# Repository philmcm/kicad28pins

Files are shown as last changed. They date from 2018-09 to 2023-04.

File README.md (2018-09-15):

Adaptation of 28-PINS PROJECT by FEDEVEL ACADEMY to KiCad
http://www.28pins.com

Adaptation by Phil McMillan, September 2018

(c) 2015 Designed by FEDEVEL Academy http://www.fedevel.com/academy. Based on Arduino: http://www.arduino.cc. Released under Creative Commons Attribution-ShareAlike 3.0 Unported.

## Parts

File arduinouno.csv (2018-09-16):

Source: | /Users/phil/Documents/Kicad/arduinouno/arduinouno.sch
Date: | Sunday, 16 September 2018 at 09:47:21 pm
Tool: | Eeschema (5.0.0-3-g5ebb6b6)
Generator: | /private/var/folders/0l/vnx5ky0j3ts2193kl5yxnbs00000gn/T/AppTranslocation/A56F1F43-A0CA-4C13-8180-FD3DEFA6E32C/d/kicad.app/Contents/SharedSupport/plugins/bom_csv_grouped_by_value.py
Component Count: | 108
Individual Components:
Item | Qty | Reference(s) | Value | LibPart | Footprint | Datasheet | Digikey
 |  | C1 | 100u|10V | arduinouno:EEE-1AA101WR | arduinouno:C_ALUM_C_SIZE | https://industrial.panasonic.com/cdbs/www-data/pdf/RDE0000/ABA0000C1145.pdf | PCE3867TR-ND
 |  | C2 | 100uF|10V | arduinouno:EEE-1AA101WR | arduinouno:C_ALUM_C_SIZE | https://industrial.panasonic.com/cdbs/www-data/pdf/RDE0000/ABA0000C1145.pdf | PCE3867TR-ND
 |  | C3 | 10uF|16V | arduinouno:C2012X5R1C106M085AC | arduinouno:C0805x145mm | https://product.tdk.com/info/en/catalog/datasheets/mlcc_commercial_general_en.pdf | 445-7645-1-ND
 |  | C4 | 100nF | arduinouno:C2012X7R1H104K085AA | arduinouno:C0805x95mm | https://product.tdk.com/info/en/catalog/datasheets/mlcc_commercial_general_en.pdf | 445-7534-1-ND
 |  | C5 | 100nF | arduinouno:C2012X7R1H104K085AA | arduinouno:C0805x95mm | https://product.tdk.com/info/en/catalog/datasheets/mlcc_commercial_general_en.pdf | 445-7534-1-ND
 |  | C6 | 100nF | arduinouno:C2012X7R1H104K085AA | arduinouno:C0805x95mm | https://product.tdk.com/info/en/catalog/datasheets/mlcc_commercial_general_en.pdf | 445-7534-1-ND
 |  | C7 | 1uF|25V | arduinouno:C2012X5R1E105K125AA | arduinouno:C0805x95mm | https://product.tdk.com/info/en/catalog/datasheets/mlcc_commercial_general_en.pdf | 445-1419-1-ND
 |  | C8 | 100nF | arduinouno:C2012X7R1H104K085AA | arduinouno:C0805x95mm | https://product.tdk.com/info/en/catalog/datasheets/mlcc_commercial_general_en.pdf | 445-7534-1-ND
 |  | C9 | 18pF | arduinouno:C0805C180J1GACTU | arduinouno:C0805x95mm | https://api.kemet.com/component-edge/download/datasheet/C0805C180J1GACTU.pdf | 399-8029-1-ND
 |  | C10 | 18pF | arduinouno:C0805C180J1GACTU | arduinouno:C0805x95mm | https://api.kemet.com/component-edge/download/datasheet/C0805C180J1GACTU.pdf | 399-8029-1-ND
 |  | C11 | 100nF | arduinouno:C2012X7R1H104K085AA | arduinouno:C0805x95mm | https://product.tdk.com/info/en/catalog/datasheets/mlcc_commercial_general_en.pdf | 445-7534-1-ND
 |  | C12 | 10uF|16V | arduinouno:C2012X5R1C106M085AC | arduinouno:C0805x145mm | https://product.tdk.com/info/en/catalog/datasheets/mlcc_commercial_general_en.pdf | 445-7645-1-ND
 |  | C13 | 10uF|16V | arduinouno:C2012X5R1C106M085AC | arduinouno:C0805x145mm | https://product.tdk.com/info/en/catalog/datasheets/mlcc_commercial_general_en.pdf | 445-7645-1-ND
 |  | C14 | 100nF | arduinouno:C2012X7R1H104K085AA | arduinouno:C0805x95mm | https://product.tdk.com/info/en/catalog/datasheets/mlcc_commercial_general_en.pdf | 445-7534-1-ND
 |  | C15 | 100nF | arduinouno:C2012X7R1H104K085AA | arduinouno:C0805x95mm | https://product.tdk.com/info/en/catalog/datasheets/mlcc_commercial_general_en.pdf | 445-7534-1-ND
 |  | C16 | 100nF | arduinouno:C2012X7R1H104K085AA | arduinouno:C0805x95mm | https://product.tdk.com/info/en/catalog/datasheets/mlcc_commercial_general_en.pdf | 445-7534-1-ND
 |  | C17 | 100nF | arduinouno:C2012X7R1H104K085AA | arduinouno:C0805x95mm | https://product.tdk.com/info/en/catalog/datasheets/mlcc_commercial_general_en.pdf | 445-7534-1-ND
 |  | C19 | 10uF|16V | arduinouno:C2012X5R1C106M085AC | arduinouno:C0805x145mm | https://product.tdk.com/info/en/catalog/datasheets/mlcc_commercial_general_en.pdf | 445-7645-1-ND
 |  | C20 | 100nF | arduinouno:C2012X7R1H104K085AA | arduinouno:C0805x95mm | https://product.tdk.com/info/en/catalog/datasheets/mlcc_commercial_general_en.pdf | 445-7534-1-ND
 |  | C21 | 10uF|16V | arduinouno:C2012X5R1C106M085AC | arduinouno:C0805x145mm | https://product.tdk.com/info/en/catalog/datasheets/mlcc_commercial_general_en.pdf | 445-7645-1-ND
 |  | C22 | 10uF|16V | arduinouno:C2012X5R1C106M085AC | arduinouno:C0805x145mm | https://product.tdk.com/info/en/catalog/datasheets/mlcc_commercial_general_en.pdf | 445-7645-1-ND
 |  | C23 | 100nF | arduinouno:C2012X7R1H104K085AA | arduinouno:C0805x95mm | https://product.tdk.com/info/en/catalog/datasheets/mlcc_commercial_general_en.pdf | 445-7534-1-ND
 |  | C24 | 100nF | arduinouno:C2012X7R1H104K085AA | arduinouno:C0805x95mm | https://product.tdk.com/info/en/catalog/datasheets/mlcc_commercial_general_en.pdf | 445-7534-1-ND
 |  | C25 | 18pF | arduinouno:C0805C180J1GACTU | arduinouno:C0805x95mm | https://api.kemet.com/component-edge/download/datasheet/C0805C180J1GACTU.pdf | 399-8029-1-ND
 |  | C26 | 100nF | arduinouno:C2012X7R1H104K085AA | arduinouno:C0805x95mm | https://product.tdk.com/info/en/catalog/datasheets/mlcc_commercial_general_en.pdf | 445-7534-1-ND
 |  | C27 | 18pF | arduinouno:C0805C180J1GACTU | arduinouno:C0805x95mm | https://api.kemet.com/component-edge/download/datasheet/C0805C180J1GACTU.pdf | 399-8029-1-ND
 |  | C28 | 100nF | arduinouno:C2012X7R1H104K085AA | arduinouno:C0805x95mm | https://product.tdk.com/info/en/catalog/datasheets/mlcc_commercial_general_en.pdf | 445-7534-1-ND
 |  | C29 | 100nF | arduinouno:C2012X7R1H104K085AA | arduinouno:C0805x95mm | https://product.tdk.com/info/en/catalog/datasheets/mlcc_commercial_general_en.pdf | 445-7534-1-ND
 |  | C30 | 100nF | arduinouno:C2012X7R1H104K085AA | arduinouno:C0805x95mm | https://product.tdk.com/info/en/catalog/datasheets/mlcc_commercial_general_en.pdf | 445-7534-1-ND
 |  | C31 | 100nF | arduinouno:C2012X7R1H104K085AA | arduinouno:C0805x95mm | https://product.tdk.com/info/en/catalog/datasheets/mlcc_commercial_general_en.pdf | 445-7534-1-ND
 |  | C32 | 100nF | arduinouno:C2012X7R1H104K085AA | arduinouno:C0805x95mm | https://product.tdk.com/info/en/catalog/datasheets/mlcc_commercial_general_en.pdf | 445-7534-1-ND
 |  | C33 | 100nF | arduinouno:C2012X7R1H104K085AA | arduinouno:C0805x95mm | https://product.tdk.com/info/en/catalog/datasheets/mlcc_commercial_general_en.pdf | 445-7534-1-ND
 |  | C34 | 10uF|16V | arduinouno:C2012X5R1C106M085AC | arduinouno:C0805x145mm | https://product.tdk.com/info/en/catalog/datasheets/mlcc_commercial_general_en.pdf | 445-7645-1-ND
 |  | D1 | GREEN | arduinouno:LG_L29K-G2J1-24-Z | arduinouno:LED_0603 | https://dammedia.osram.info/media/resource/hires/osram-dam-2493945/LG%20L29K.pdf | 475-2709-1-ND
 |  | D2 | ORANGE | arduinouno:LO_L29K-H2K1-24-Z | arduinouno:LED_0603 | https://dammedia.osram.info/media/resource/hires/osram-dam-2493882/LO%20L29K.pdf | 475-2740-1-ND
 |  | D3 | ORANGE | arduinouno:LO_L29K-H2K1-24-Z | arduinouno:LED_0603 | https://dammedia.osram.info/media/resource/hires/osram-dam-2493882/LO%20L29K.pdf | 475-2740-1-ND
 |  | D4 | ORANGE | arduinouno:LO_L29K-H2K1-24-Z | arduinouno:LED_0603 | https://dammedia.osram.info/media/resource/hires/osram-dam-2493882/LO%20L29K.pdf | 475-2740-1-ND
 |  | D5 | BAT54HT1G | arduinouno:BAT54HT1G | arduinouno:SOD323 | http://www.onsemi.com/pub/Collateral/BAT54HT1-D.PDF | BAT54HT1GOSTR-ND
 |  | D6 | BAT54HT1G | arduinouno:BAT54HT1G | arduinouno:SOD323 | http://www.onsemi.com/pub/Collateral/BAT54HT1-D.PDF | BAT54HT1GOSTR-ND
 |  | FB1 | MPZ2012S601AT000 | arduinouno:MPZ2012S601AT000 | arduinouno:FB0805x85mm | https://product.tdk.com/info/en/catalog/datasheets/beads_commercial_power_mpz2012_en.pdf | 445-7645-1-ND
 |  | FB2 | MPZ2012S601AT000 | arduinouno:MPZ2012S601AT000 | arduinouno:FB0805x85mm | https://product.tdk.com/info/en/catalog/datasheets/beads_commercial_power_mpz2012_en.pdf | 445-7645-1-ND
 |  | FB3 | MPZ2012S601AT000 | arduinouno:MPZ2012S601AT000 | arduinouno:FB0805x85mm | https://product.tdk.com/info/en/catalog/datasheets/beads_commercial_power_mpz2012_en.pdf | 445-7645-1-ND
 |  | FID1 | FID_1MM | arduinouno:FID_1MM | arduinouno:FID_40x120M
 |  | FID2 | FID_1MM | arduinouno:FID_1MM | arduinouno:FID_40x120M
 |  | FID3 | FID_1MM | arduinouno:FID_1MM | arduinouno:FID_40x120M
 |  | FID4 | FID_1MM | arduinouno:FID_1MM | arduinouno:FID_40x120M
 |  | J1 | M20-7820842 | arduinouno:M20-7820842 | arduinouno:8P_Header_Female_2.54mm | https://cdn.harwin.com/pdfs/M20-782.pdf | 952-1823-ND
 |  | J2 | M20-7820646 | arduinouno:M20-7820646 | arduinouno:6P_Header_Female_2.54mm | https://cdn.harwin.com/pdfs/M20-782.pdf | 952-1809-ND
 |  | J3 | M20-7820842 | arduinouno:M20-7820842 | arduinouno:8P_Header_Female_2.54mm | https://cdn.harwin.com/pdfs/M20-782.pdf | 952-1823-ND
 |  | J4 | M20-7821046 | arduinouno:M20-7821046 | arduinouno:10P_Header_Female_2.54mm | https://cdn.harwin.com/pdfs/M20-782.pdf | 952-1847-ND
 |  | J5 | 67997-106HLF | arduinouno:67997-106HLF | arduinouno:HDR_2x3_2.54mm | https://cdn.amphenol-icc.com/media/wysiwyg/files/drawing/67996.pdf | 609-3393-ND
 |  | J6 | 67997-106HLF | arduinouno:67997-106HLF | arduinouno:HDR_2x3_2.54mm | https://cdn.amphenol-icc.com/media/wysiwyg/files/drawing/67996.pdf | 609-3393-ND
 |  | J7 | 10118193-0001LF | arduinouno:10118193-0001LF | arduinouno:10118193 | https://cdn.amphenol-icc.com/media/wysiwyg/files/drawing/10118193.pdf | 609-4616-1-ND
 |  | J8 | PAD_WITH_HOLE_4mmx1.5mm | arduinouno:PAD_WITH_HOLE_4mmx1.5mm | arduinouno:PAD_WITH_HOLE_4mmx1.5mm
 |  | J9 | PAD_WITH_HOLE_4mmx1.5mm | arduinouno:PAD_WITH_HOLE_4mmx1.5mm | arduinouno:PAD_WITH_HOLE_4mmx1.5mm
 |  | JP1 | 68000-103HLF | arduinouno:68000-103HLF | arduinouno:3P_Header_2.54mm | https://cdn.amphenol-icc.com/media/wysiwyg/files/drawing/68000.pdf | 609-3461-ND
 |  | JP2 | 68602-104HLF | arduinouno:68602-104HLF | arduinouno:HDR_2x2_2.54mm | https://cdn.amphenol-icc.com/media/wysiwyg/files/drawing/67996.pdf | 609-3361-ND
 |  | JP3 | 68001-204HLF | arduinouno:68001-204HLF | arduinouno:4P_Header_2.54mm | https://cdn.amphenol-icc.com/media/wysiwyg/files/drawing/68000.pdf | 609-3402-ND
 |  | JP4 | 68000-103HLF | arduinouno:68000-103HLF | arduinouno:3P_Header_2.54mm | https://cdn.amphenol-icc.com/media/wysiwyg/files/drawing/68000.pdf | 609-3461-ND
 |  | L1 | 2u2|2A | arduinouno:L1210R2R2MDWIT | arduinouno:C1210_INDUCTOR | https://api.kemet.com/component-edge/download/datasheet/L1210R2R2MDWIT.pdf | 399-9598-1-ND
 |  | LINK1 | QPC02SXGN-RC | arduinouno:QPC02SXGN-RC |  | https://drawings-pdf.s3.amazonaws.com/11510.pdf | S9337-ND
 |  | LINK2 | QPC02SXGN-RC | arduinouno:QPC02SXGN-RC |  | https://drawings-pdf.s3.amazonaws.com/11510.pdf | S9337-ND
 |  | LINK3 | QPC02SXGN-RC | arduinouno:QPC02SXGN-RC |  | https://drawings-pdf.s3.amazonaws.com/11510.pdf | S9337-ND
 |  | MH1 | MH_7.4MMCx3.2MMD | arduinouno:MH_7.4MMCx3.2MMD | arduinouno:MH_7.4MMCx3.2MMD
 |  | MH2 | MH_7.4MMCx3.2MMD | arduinouno:MH_7.4MMCx3.2MMD | arduinouno:MH_7.4MMCx3.2MMD
 |  | MH3 | MH_7.4MMCx3.2MMD | arduinouno:MH_7.4MMCx3.2MMD | arduinouno:MH_7.4MMCx3.2MMD
 |  | MH4 | MH_7.4MMNCx3.2MMD | arduinouno:MH_7.4MMNCx3.2MMD | arduinouno:MH_7.4MMCx3.2MMD_NON_COPPER_NPTH
 |  | R1 | 100K | arduinouno:RC0805FR-07100KL | arduinouno:R0805x60mm | http://www.yageo.com/documents/recent/PYu-RC_Group_51_RoHS_L_9.pdf | 311-100KCRCT-ND
 |  | R2 | 560R | arduinouno:RC0805FR-07560RL | arduinouno:R0805x60mm | http://www.yageo.com/documents/recent/PYu-RC_Group_51_RoHS_L_9.pdf | 311-560CRCT-ND
 |  | R3 | 560R | arduinouno:RC0805FR-07560RL | arduinouno:R0805x60mm | http://www.yageo.com/documents/recent/PYu-RC_Group_51_RoHS_L_9.pdf | 311-560CRCT-ND
 |  | R4 | 10k | arduinouno:RC0805FR-0710KL | arduinouno:R0805x60mm | http://www.yageo.com/documents/recent/PYu-RC_Group_51_RoHS_L_9.pdf | 311-10.0KCRCT-ND
 |  | R5 | 22R | arduinouno:RC0805FR-0722RL | arduinouno:R0805x60mm | http://www.yageo.com/documents/recent/PYu-RC_Group_51_RoHS_L_9.pdf | 311-22.0CRCT-ND
 |  | R6 | 22R | arduinouno:RC0805FR-0722RL | arduinouno:R0805x60mm | http://www.yageo.com/documents/recent/PYu-RC_Group_51_RoHS_L_9.pdf | 311-22.0CRCT-ND
 |  | R7 | 22R | arduinouno:RC0805FR-0722RL | arduinouno:R0805x60mm | http://www.yageo.com/documents/recent/PYu-RC_Group_51_RoHS_L_9.pdf | 311-22.0CRCT-ND
 |  | R8 | 0R | arduinouno:RC0805JR-070RL | arduinouno:R0805x60mm | http://www.yageo.com/documents/recent/PYu-RC_Group_51_RoHS_L_9.pdf | 311-0.0ARCT-ND
 |  | R9 | 1M | arduinouno:RC0805FR-071ML | arduinouno:R0805x60mm | http://www.yageo.com/documents/recent/PYu-RC_Group_51_RoHS_L_9.pdf | 311-1.00MCRCT-ND
 |  | R10 | 1k | arduinouno:RC0805FR-071KL | arduinouno:R0805x60mm | http://www.yageo.com/documents/recent/PYu-RC_Group_51_RoHS_L_9.pdf | 311-1.00KCRCT-ND
 |  | R11 | 1k | arduinouno:RC0805FR-071KL | arduinouno:R0805x60mm | http://www.yageo.com/documents/recent/PYu-RC_Group_51_RoHS_L_9.pdf | 311-1.00KCRCT-ND
 |  | R12 | 1k | arduinouno:RC0805FR-071KL | arduinouno:R0805x60mm | http://www.yageo.com/documents/recent/PYu-RC_Group_51_RoHS_L_9.pdf | 311-1.00KCRCT-ND
 |  | R13 | 22R | arduinouno:RC0805FR-0722RL | arduinouno:R0805x60mm | http://www.yageo.com/documents/recent/PYu-RC_Group_51_RoHS_L_9.pdf | 311-22.0CRCT-ND
 |  | R14 | 10k | arduinouno:RC0805FR-0710KL | arduinouno:R0805x60mm | http://www.yageo.com/documents/recent/PYu-RC_Group_51_RoHS_L_9.pdf | 311-10.0KCRCT-ND
 |  | R15 | 560R | arduinouno:RC0805FR-07560RL | arduinouno:R0805x60mm | http://www.yageo.com/documents/recent/PYu-RC_Group_51_RoHS_L_9.pdf | 311-560CRCT-ND
 |  | R16 | 1M | arduinouno:RC0805FR-071ML | arduinouno:R0805x60mm | http://www.yageo.com/documents/recent/PYu-RC_Group_51_RoHS_L_9.pdf | 311-1.00MCRCT-ND
 |  | R17 | 560R | arduinouno:RC0805FR-07560RL | arduinouno:R0805x60mm | http://www.yageo.com/documents/recent/PYu-RC_Group_51_RoHS_L_9.pdf | 311-560CRCT-ND
 |  | R18 | 10k | arduinouno:RC0805FR-0710KL | arduinouno:R0805x60mm | http://www.yageo.com/documents/recent/PYu-RC_Group_51_RoHS_L_9.pdf | 311-10.0KCRCT-ND
 |  | R19 | 10k | arduinouno:RC0805FR-0710KL | arduinouno:R0805x60mm | http://www.yageo.com/documents/recent/PYu-RC_Group_51_RoHS_L_9.pdf | 311-10.0KCRCT-ND
 |  | R20 | 10k | arduinouno:RC0805FR-0710KL | arduinouno:R0805x60mm | http://www.yageo.com/documents/recent/PYu-RC_Group_51_RoHS_L_9.pdf | 311-10.0KCRCT-ND
 |  | R21 | 10k | arduinouno:RC0805FR-0710KL | arduinouno:R0805x60mm | http://www.yageo.com/documents/recent/PYu-RC_Group_51_RoHS_L_9.pdf | 311-10.0KCRCT-ND
 |  | R22 | 560R | arduinouno:RC0805FR-07560RL | arduinouno:R0805x60mm | http://www.yageo.com/documents/recent/PYu-RC_Group_51_RoHS_L_9.pdf | 311-560CRCT-ND
 |  | R23 | 22R | arduinouno:RC0805FR-0722RL | arduinouno:R0805x60mm | http://www.yageo.com/documents/recent/PYu-RC_Group_51_RoHS_L_9.pdf | 311-22.0CRCT-ND
 |  | R24 | 22R | arduinouno:RC0805FR-0722RL | arduinouno:R0805x60mm | http://www.yageo.com/documents/recent/PYu-RC_Group_51_RoHS_L_9.pdf | 311-22.0CRCT-ND
 |  | R25 | 22R | arduinouno:RC0805FR-0722RL | arduinouno:R0805x60mm | http://www.yageo.com/documents/recent/PYu-RC_Group_51_RoHS_L_9.pdf | 311-22.0CRCT-ND
 |  | R27 | 0R | arduinouno:RC0805JR-070RL | arduinouno:R0805x60mm | http://www.yageo.com/documents/recent/PYu-RC_Group_51_RoHS_L_9.pdf | 311-0.0ARCT-ND
 |  | R28 | 0R | arduinouno:RC0805JR-070RL | arduinouno:R0805x60mm | http://www.yageo.com/documents/recent/PYu-RC_Group_51_RoHS_L_9.pdf | 311-0.0ARCT-ND
 |  | SCKT_FOR_U1 | 28-DIP Socket | arduinouno:4828-3004-CP | arduinouno:28DIP_7.62MM_SCKT | http://multimedia.3m.com/mws/media/218496O/3mtm-dip-socket-4800-series-ts1099.pdf | 3M5480-ND
 |  | SW1 | 1825910-6 | arduinouno:1825910-6 | arduinouno:1825910-6 | http://www.te.com/commerce/DocumentDelivery/DDEController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 | 450-1650-ND
 |  | SW2 | 1825910-6 | arduinouno:1825910-6 | arduinouno:1825910-6 | http://www.te.com/commerce/DocumentDelivery/DDEController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 | 450-1650-ND
 |  | U1 | ATMEGA328P-PU | arduinouno:ATMEGA328P-PU | arduinouno:28PIN_PDIP_7.62mm | http://www.microchip.com/mymicrochip/filehandler.aspx?ddocname=en589967 | ATMEGA328P-PU-ND
 |  | U2 | ATMEGA16U2-AU | arduinouno:ATMEGA16U2-AU | arduinouno:QFP-32_8.4x8.4_Pitch0.8mm | http://ww1.microchip.com/downloads/en/DeviceDoc/doc7799.pdf | ATMEGA16U2-AU-ND
 |  | U3 | TL1963A-33DCQR | arduinouno:TL1963A-33DCQR | arduinouno:DCQ_R-PDSO-G6 | http://www.ti.com/lit/ds/symlink/tl1963a.pdf | 296-24534-1-ND
 |  | U4 | SN74AHC1G09DBVR | arduinouno:SN74AHC1G09DBVR | arduinouno:DBV_SOT23_5 | http://www.ti.com/lit/ds/symlink/sn74ahc1g09.pdf | 296-29202-1-ND
 |  | U5 | SN74AHC1G09DBVR | arduinouno:SN74AHC1G09DBVR | arduinouno:DBV_SOT23_5 | http://www.ti.com/lit/ds/symlink/sn74ahc1g09.pdf | 296-29202-1-ND
 |  | U6 | SN74AHC1G09DBVR | arduinouno:SN74AHC1G09DBVR | arduinouno:DBV_SOT23_5 | http://www.ti.com/lit/ds/symlink/sn74ahc1g09.pdf | 296-29202-1-ND
 |  | U7 | SN74AHC1G09DBVR | arduinouno:SN74AHC1G09DBVR | arduinouno:DBV_SOT23_5 | http://www.ti.com/lit/ds/symlink/sn74ahc1g09.pdf | 296-29202-1-ND
 |  | Y1 | 16.000MHz | arduinouno:ABM7-16.000MHZ-D2Y-T | arduinouno:ABM7_BIG | https://abracon.com/Resonators/abm7.pdf | 535-9840-1-ND
 |  | Y2 | 16.000MHz | arduinouno:ABM7-16.000MHZ-D2Y-T | arduinouno:ABM7_BIG | https://abracon.com/Resonators/abm7.pdf | 535-9840-1-ND
 |  | Z1 | CG0603MLC-05E | arduinouno:CG0603MLC-05E | arduinouno:R_0603 | https://www.bourns.com/docs/Product-Datasheets/MLC.pdf | CG0603MLC-05ECT-ND
 |  | Z2 | CG0603MLC-05E | arduinouno:CG0603MLC-05E | arduinouno:R_0603 | https://www.bourns.com/docs/Product-Datasheets/MLC.pdf | CG0603MLC-05ECT-ND
Collated Components:
Item | Qty | Reference(s) | Value | LibPart | Footprint | Datasheet | Digikey
1 | 1 | C1 | 100u|10V | arduinouno:EEE-1AA101WR | arduinouno:C_ALUM_C_SIZE | https://industrial.panasonic.com/cdbs/www-data/pdf/RDE0000/ABA0000C1145.pdf | PCE3867TR-ND
2 | 1 | C2 | 100uF|10V | arduinouno:EEE-1AA101WR | arduinouno:C_ALUM_C_SIZE | https://industrial.panasonic.com/cdbs/www-data/pdf/RDE0000/ABA0000C1145.pdf | PCE3867TR-ND
3 | 7 | C3, C12, C13, C19, C21, C22, C34 | 10uF|16V | arduinouno:C2012X5R1C106M085AC | arduinouno:C0805x145mm | https://product.tdk.com/info/en/catalog/datasheets/mlcc_commercial_general_en.pdf | 445-7645-1-ND
4 | 19 | C4, C5, C6, C8, C11, C14, C15, C16, C17, C20, C23, C24, C26, C28, C29, C30, C31, C32, C33 | 100nF | arduinouno:C2012X7R1H104K085AA | arduinouno:C0805x95mm | https://product.tdk.com/info/en/catalog/datasheets/mlcc_commercial_general_en.pdf | 445-7534-1-ND
5 | 1 | C7 | 1uF|25V | arduinouno:C2012X5R1E105K125AA | arduinouno:C0805x95mm | https://product.tdk.com/info/en/catalog/datasheets/mlcc_commercial_general_en.pdf | 445-1419-1-ND
6 | 4 | C9, C10, C25, C27 | 18pF | arduinouno:C0805C180J1GACTU | arduinouno:C0805x95mm | https://api.kemet.com/component-edge/download/datasheet/C0805C180J1GACTU.pdf | 399-8029-1-ND
7 | 1 | D1 | GREEN | arduinouno:LG_L29K-G2J1-24-Z | arduinouno:LED_0603 | https://dammedia.osram.info/media/resource/hires/osram-dam-2493945/LG%20L29K.pdf | 475-2709-1-ND
8 | 3 | D2, D3, D4 | ORANGE | arduinouno:LO_L29K-H2K1-24-Z | arduinouno:LED_0603 | https://dammedia.osram.info/media/resource/hires/osram-dam-2493882/LO%20L29K.pdf | 475-2740-1-ND
9 | 2 | D5, D6 | BAT54HT1G | arduinouno:BAT54HT1G | arduinouno:SOD323 | http://www.onsemi.com/pub/Collateral/BAT54HT1-D.PDF | BAT54HT1GOSTR-ND
10 | 3 | FB1, FB2, FB3 | MPZ2012S601AT000 | arduinouno:MPZ2012S601AT000 | arduinouno:FB0805x85mm | https://product.tdk.com/info/en/catalog/datasheets/beads_commercial_power_mpz2012_en.pdf | 445-7645-1-ND
11 | 4 | FID1, FID2, FID3, FID4 | FID_1MM | arduinouno:FID_1MM | arduinouno:FID_40x120M
12 | 2 | J1, J3 | M20-7820842 | arduinouno:M20-7820842 | arduinouno:8P_Header_Female_2.54mm | https://cdn.harwin.com/pdfs/M20-782.pdf | 952-1823-ND
13 | 1 | J2 | M20-7820646 | arduinouno:M20-7820646 | arduinouno:6P_Header_Female_2.54mm | https://cdn.harwin.com/pdfs/M20-782.pdf | 952-1809-ND
14 | 1 | J4 | M20-7821046 | arduinouno:M20-7821046 | arduinouno:10P_Header_Female_2.54mm | https://cdn.harwin.com/pdfs/M20-782.pdf | 952-1847-ND
15 | 2 | J5, J6 | 67997-106HLF | arduinouno:67997-106HLF | arduinouno:HDR_2x3_2.54mm | https://cdn.amphenol-icc.com/media/wysiwyg/files/drawing/67996.pdf | 609-3393-ND
16 | 1 | J7 | 10118193-0001LF | arduinouno:10118193-0001LF | arduinouno:10118193 | https://cdn.amphenol-icc.com/media/wysiwyg/files/drawing/10118193.pdf | 609-4616-1-ND
17 | 2 | J8, J9 | PAD_WITH_HOLE_4mmx1.5mm | arduinouno:PAD_WITH_HOLE_4mmx1.5mm | arduinouno:PAD_WITH_HOLE_4mmx1.5mm
18 | 2 | JP1, JP4 | 68000-103HLF | arduinouno:68000-103HLF | arduinouno:3P_Header_2.54mm | https://cdn.amphenol-icc.com/media/wysiwyg/files/drawing/68000.pdf | 609-3461-ND
19 | 1 | JP2 | 68602-104HLF | arduinouno:68602-104HLF | arduinouno:HDR_2x2_2.54mm | https://cdn.amphenol-icc.com/media/wysiwyg/files/drawing/67996.pdf | 609-3361-ND
20 | 1 | JP3 | 68001-204HLF | arduinouno:68001-204HLF | arduinouno:4P_Header_2.54mm | https://cdn.amphenol-icc.com/media/wysiwyg/files/drawing/68000.pdf | 609-3402-ND
21 | 1 | L1 | 2u2|2A | arduinouno:L1210R2R2MDWIT | arduinouno:C1210_INDUCTOR | https://api.kemet.com/component-edge/download/datasheet/L1210R2R2MDWIT.pdf | 399-9598-1-ND
22 | 3 | LINK1, LINK2, LINK3 | QPC02SXGN-RC | arduinouno:QPC02SXGN-RC |  | https://drawings-pdf.s3.amazonaws.com/11510.pdf | S9337-ND
23 | 3 | MH1, MH2, MH3 | MH_7.4MMCx3.2MMD | arduinouno:MH_7.4MMCx3.2MMD | arduinouno:MH_7.4MMCx3.2MMD
24 | 1 | MH4 | MH_7.4MMNCx3.2MMD | arduinouno:MH_7.4MMNCx3.2MMD | arduinouno:MH_7.4MMCx3.2MMD_NON_COPPER_NPTH
25 | 1 | R1 | 100K | arduinouno:RC0805FR-07100KL | arduinouno:R0805x60mm | http://www.yageo.com/documents/recent/PYu-RC_Group_51_RoHS_L_9.pdf | 311-100KCRCT-ND
26 | 5 | R2, R3, R15, R17, R22 | 560R | arduinouno:RC0805FR-07560RL | arduinouno:R0805x60mm | http://www.yageo.com/documents/recent/PYu-RC_Group_51_RoHS_L_9.pdf | 311-560CRCT-ND
27 | 6 | R4, R14, R18, R19, R20, R21 | 10k | arduinouno:RC0805FR-0710KL | arduinouno:R0805x60mm | http://www.yageo.com/documents/recent/PYu-RC_Group_51_RoHS_L_9.pdf | 311-10.0KCRCT-ND
28 | 7 | R5, R6, R7, R13, R23, R24, R25 | 22R | arduinouno:RC0805FR-0722RL | arduinouno:R0805x60mm | http://www.yageo.com/documents/recent/PYu-RC_Group_51_RoHS_L_9.pdf | 311-22.0CRCT-ND
29 | 3 | R8, R27, R28 | 0R | arduinouno:RC0805JR-070RL | arduinouno:R0805x60mm | http://www.yageo.com/documents/recent/PYu-RC_Group_51_RoHS_L_9.pdf | 311-0.0ARCT-ND
30 | 2 | R9, R16 | 1M | arduinouno:RC0805FR-071ML | arduinouno:R0805x60mm | http://www.yageo.com/documents/recent/PYu-RC_Group_51_RoHS_L_9.pdf | 311-1.00MCRCT-ND
31 | 3 | R10, R11, R12 | 1k | arduinouno:RC0805FR-071KL | arduinouno:R0805x60mm | http://www.yageo.com/documents/recent/PYu-RC_Group_51_RoHS_L_9.pdf | 311-1.00KCRCT-ND
32 | 1 | SCKT_FOR_U1 | 28-DIP Socket | arduinouno:4828-3004-CP | arduinouno:28DIP_7.62MM_SCKT | http://multimedia.3m.com/mws/media/218496O/3mtm-dip-socket-4800-series-ts1099.pdf | 3M5480-ND
33 | 2 | SW1, SW2 | 1825910-6 | arduinouno:1825910-6 | arduinouno:1825910-6 | http://www.te.com/commerce/DocumentDelivery/DDEController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 | 450-1650-ND
34 | 1 | U1 | ATMEGA328P-PU | arduinouno:ATMEGA328P-PU | arduinouno:28PIN_PDIP_7.62mm | http://www.microchip.com/mymicrochip/filehandler.aspx?ddocname=en589967 | ATMEGA328P-PU-ND
35 | 1 | U2 | ATMEGA16U2-AU | arduinouno:ATMEGA16U2-AU | arduinouno:QFP-32_8.4x8.4_Pitch0.8mm | http://ww1.microchip.com/downloads/en/DeviceDoc/doc7799.pdf | ATMEGA16U2-AU-ND
36 | 1 | U3 | TL1963A-33DCQR | arduinouno:TL1963A-33DCQR | arduinouno:DCQ_R-PDSO-G6 | http://www.ti.com/lit/ds/symlink/tl1963a.pdf | 296-24534-1-ND
37 | 4 | U4, U5, U6, U7 | SN74AHC1G09DBVR | arduinouno:SN74AHC1G09DBVR | arduinouno:DBV_SOT23_5 | http://www.ti.com/lit/ds/symlink/sn74ahc1g09.pdf | 296-29202-1-ND
38 | 2 | Y1, Y2 | 16.000MHz | arduinouno:ABM7-16.000MHZ-D2Y-T | arduinouno:ABM7_BIG | https://abracon.com/Resonators/abm7.pdf | 535-9840-1-ND
39 | 2 | Z1, Z2 | CG0603MLC-05E | arduinouno:CG0603MLC-05E | arduinouno:R_0603 | https://www.bourns.com/docs/Product-Datasheets/MLC.pdf | CG0603MLC-05ECT-ND

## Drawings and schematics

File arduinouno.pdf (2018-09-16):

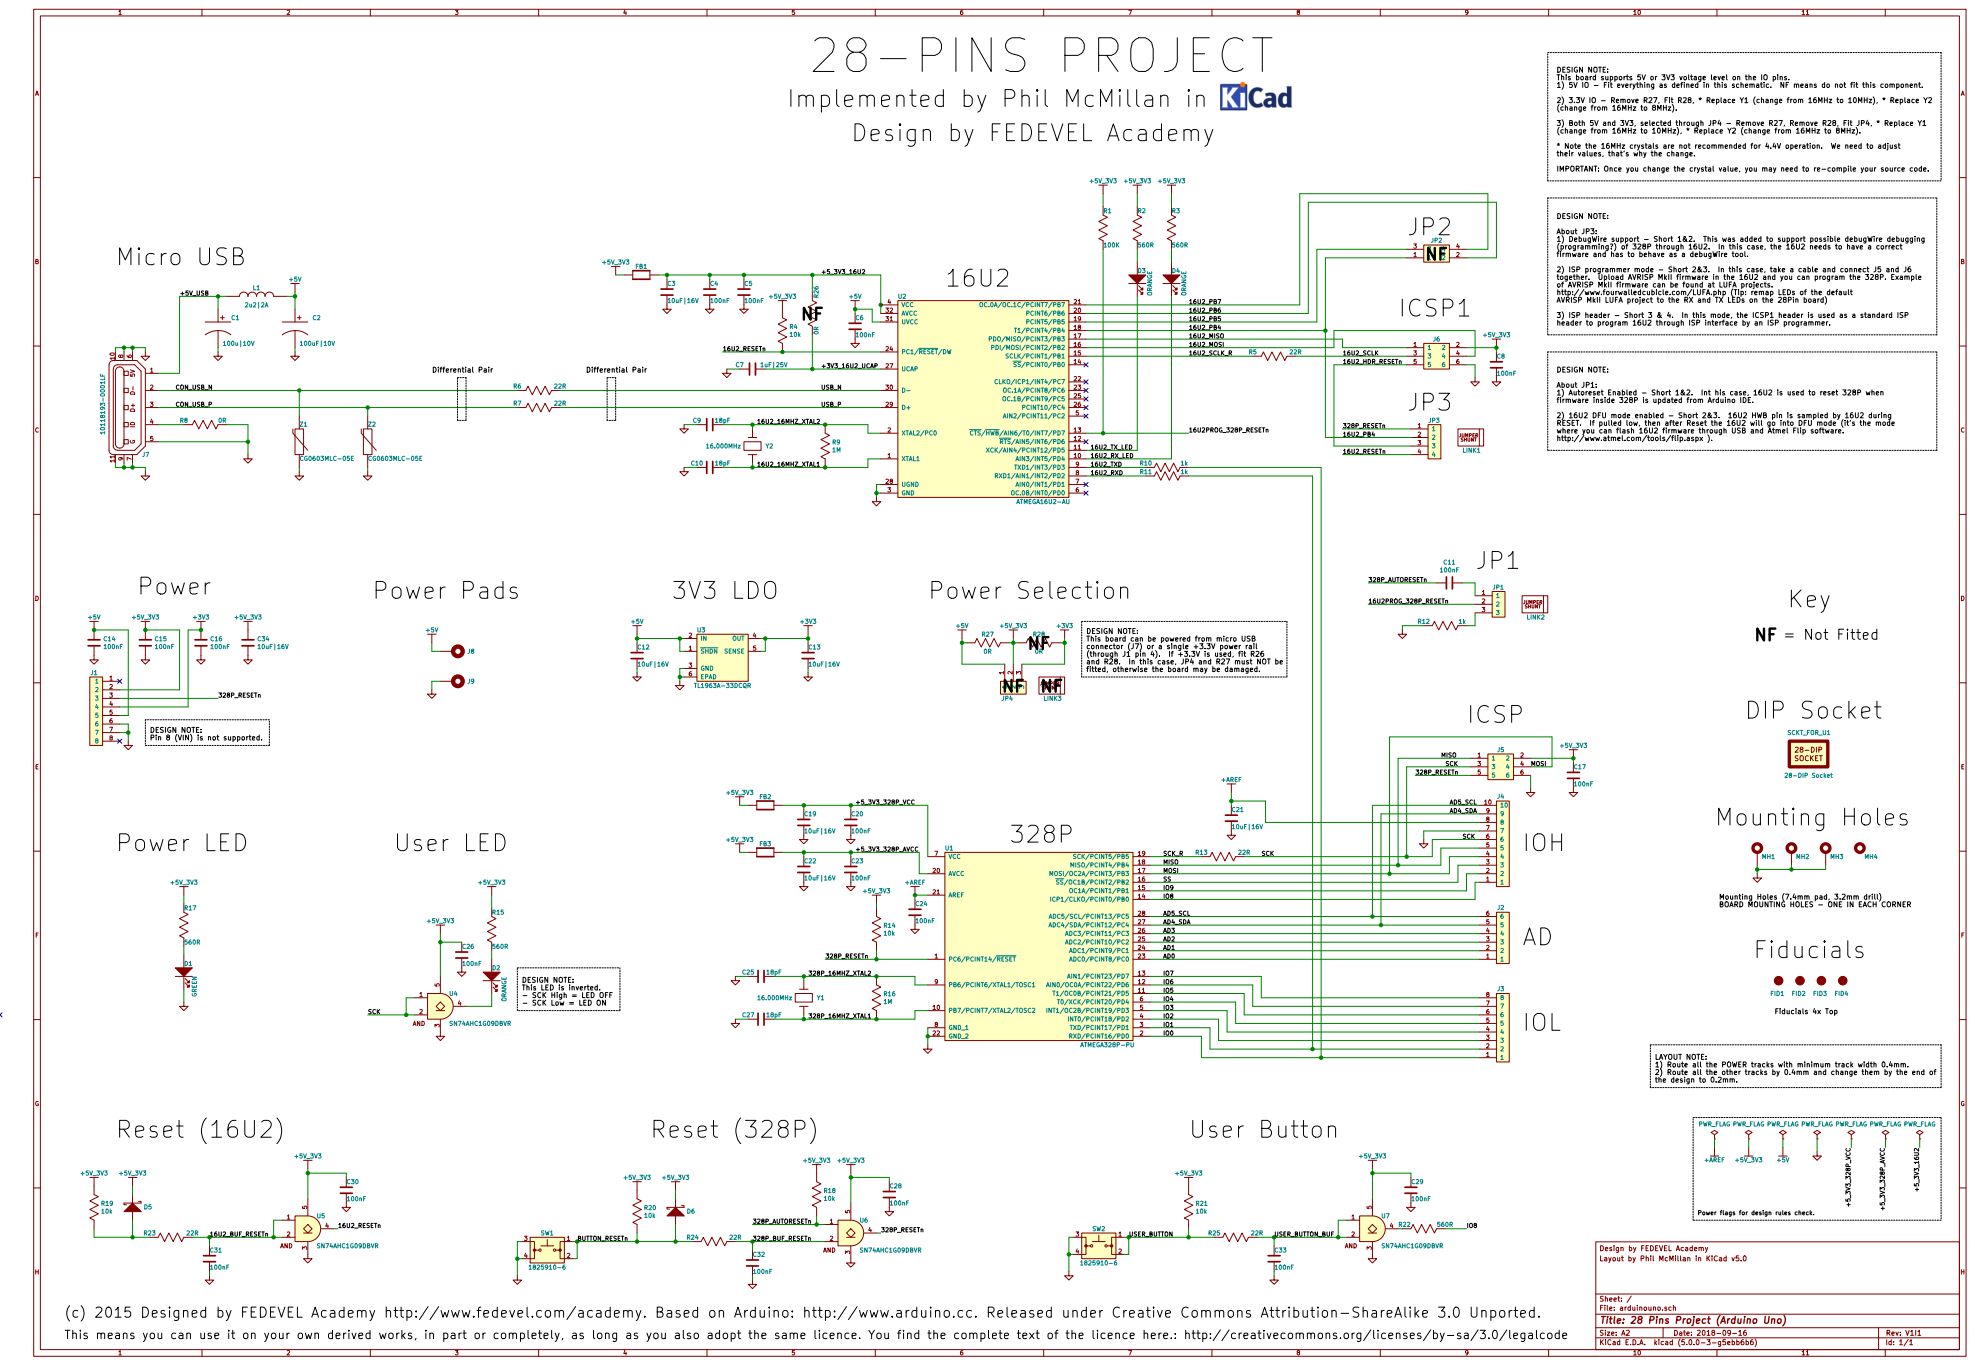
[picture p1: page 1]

DESIGN NOTE: This board supports 5V or 3V3 voltage level on the IO pins.
1) 5V IO - Fit everything as defined in this schematic. NF means do not fit this component.
2) 3.3V IO - Remove R27, Fit R28, * Replace Y1 (change from 16MHz to 10MHz), * Replace Y2
(change from 16MHz to 8MHz).
3) Both 5V and 3V3, selected through JP4 - Remove R27, Remove R28, Fit JP4, * Replace Y1
(change from 16MHz to 10MHz), * Replace Y2 (change from 16MHz to 8MHz).
* Note the 16MHz crystals are not recommended for 4.4V operation. We need to adjust
their values, thats why the change.
IMPORTANT: Once you change the crystal value, you may need to re-compile your source code. DESIGN NOTE: About JP3: 1) DebugWire support - Short 1&2. This was added to support possible debugWire debugging

Implemented by Phil McMillan in
Design by FEDEVEL Academy

3 1 | 4

(programming?) of 328P through 16U2. In this case, the 16U2 needs to have a correct
firmware and has to behave as a debugWire tool.
2) ISP programmer mode - Short 2&3. In this case, take a cable and connect J5 and J6
together. Upload AVRISP MkII firmware in the 16U2 and you can program the 328P. Example
of AVRISP MkII firmware can be found at LUFA projects.
http://www.fourwalledcubicle.com/LUFA.php (Tip: remap LEDs of the default
AVRISP MkII LUFA project to the RX and TX LEDs on the 28Pin board)
3) ISP header - Short 3 & 4. In this mode, the ICSP1 header is used as a standard ISP
header to program 16U2 through ISP interface by an ISP programmer. DESIGN NOTE: About JP1: 1) Autoreset Enabled - Short 1&2. Int his case, 16U2 is used to reset 328P when

http://www.atmel.com/tools/flip.aspx ). R26 0R

16U2_PB6
16U2_PB5

16U2_MOSI 16U2_MISO

16U2_SCLK_R | 16U2_SCLK 3 | 4

firmware inside 328P is updated from Arduino IDE.
2) 16U2 DFU mode enabled - Short 2&3. 16U2 HWB pin is sampled by 16U2 during
RESET. If pulled low, then after Reset the 16U2 will go into DFU mode (its the mode
where you can flash 16U2 firmware through USB and Atmel Flip software.

DESIGN NOTE: This board can be powered from micro USB
connector (J7) or a single +3.3V power rail
(through J1 pin 4). If +3.3V is used, fit R26
and R28. In this case, JP4 and R27 must NOT be
fitted, otherwise the board may be damaged.

Mounting Holes (7.4mm pad, 3.2mm drill) BOARD MOUNTING HOLES - ONE IN EACH CORNER
Fiducials

IO7 AD0 AD1 AD2 AD3 AD4_SDA | 3

DESIGN NOTE: This LED is inverted. - SCK High = LED OFF

- SCK Low = LED ON

LAYOUT NOTE: 1) Route all the POWER tracks with minimum track width 0.4mm.
2) Route all the other tracks by 0.4mm and change them by the end of
the design to 0.2mm.

Power flags for design rules check.

Id: 1/1 Title: 28 Pins Project (Arduino Uno) File: arduinouno.sch Sheet: / Layout by Phil McMillan in KiCad v5.0

(c) 2015 Designed by FEDEVEL Academy http://www.fedevel.com/academy. Based on Arduino: http://www.arduino.cc. Released under Creative Commons Attribution-ShareAlike 3.0 Unported.
This means you can use it on your own derived works, in part or completely, as long as you also adopt the same licence. You find the complete text of the licence here.: http://creativecommons.org/licenses/by-sa/3.0/legalcode

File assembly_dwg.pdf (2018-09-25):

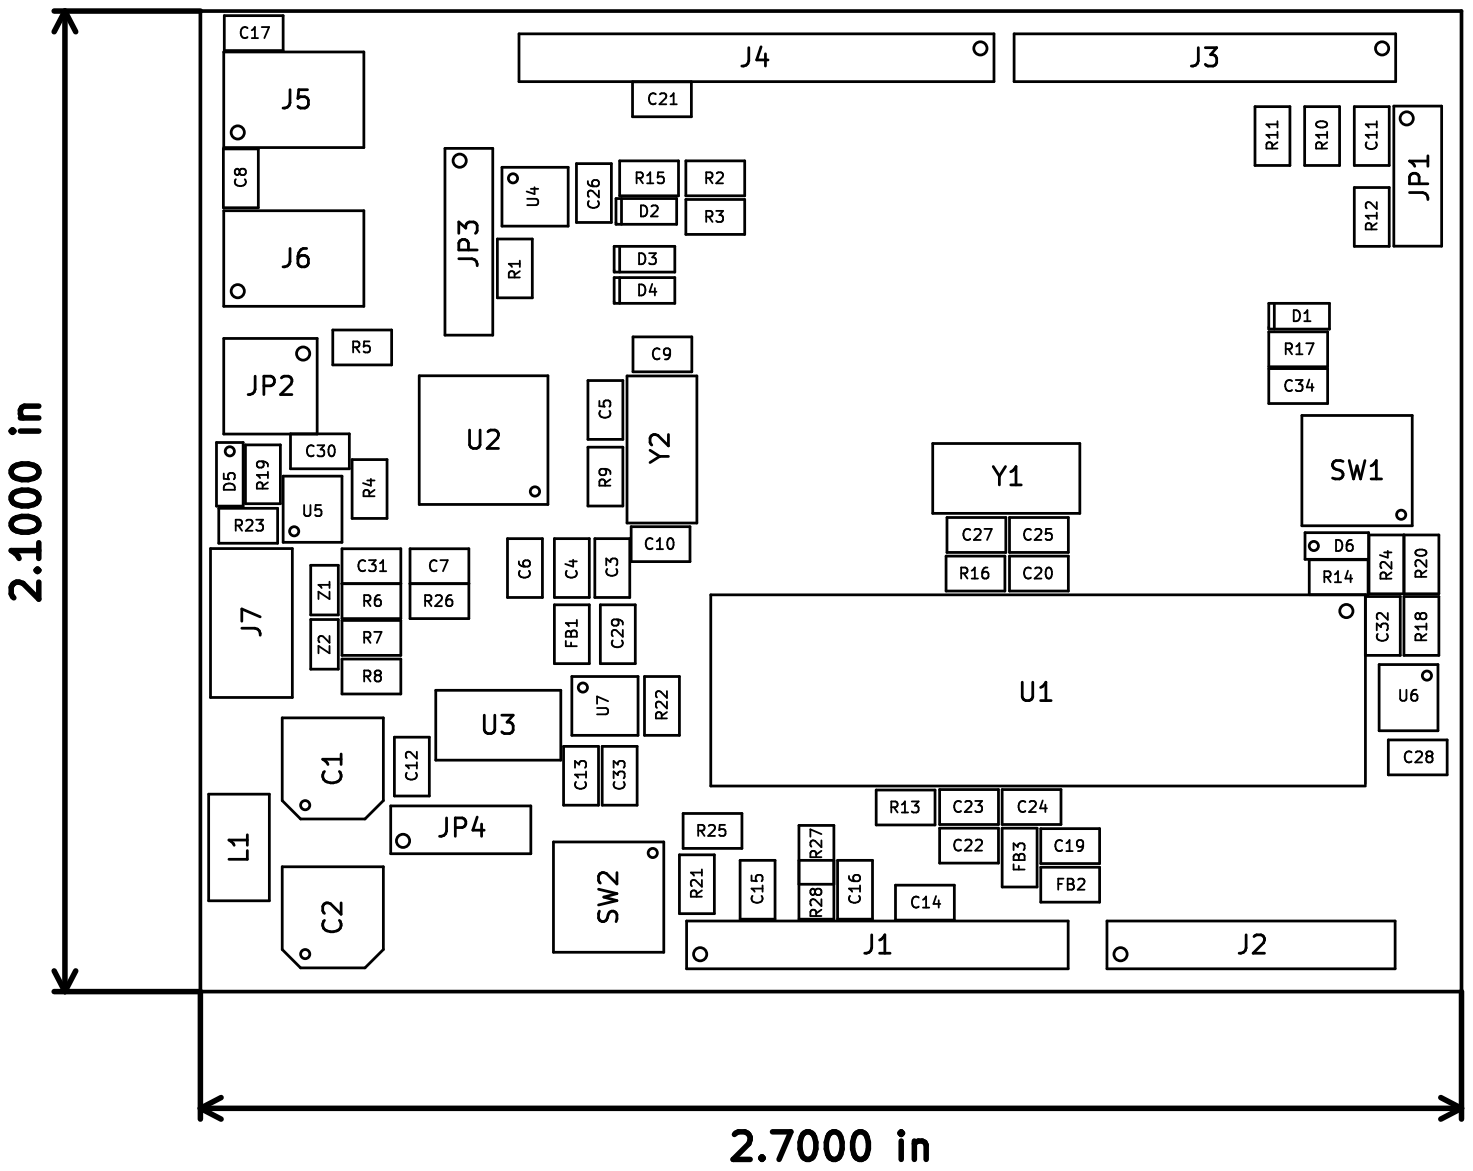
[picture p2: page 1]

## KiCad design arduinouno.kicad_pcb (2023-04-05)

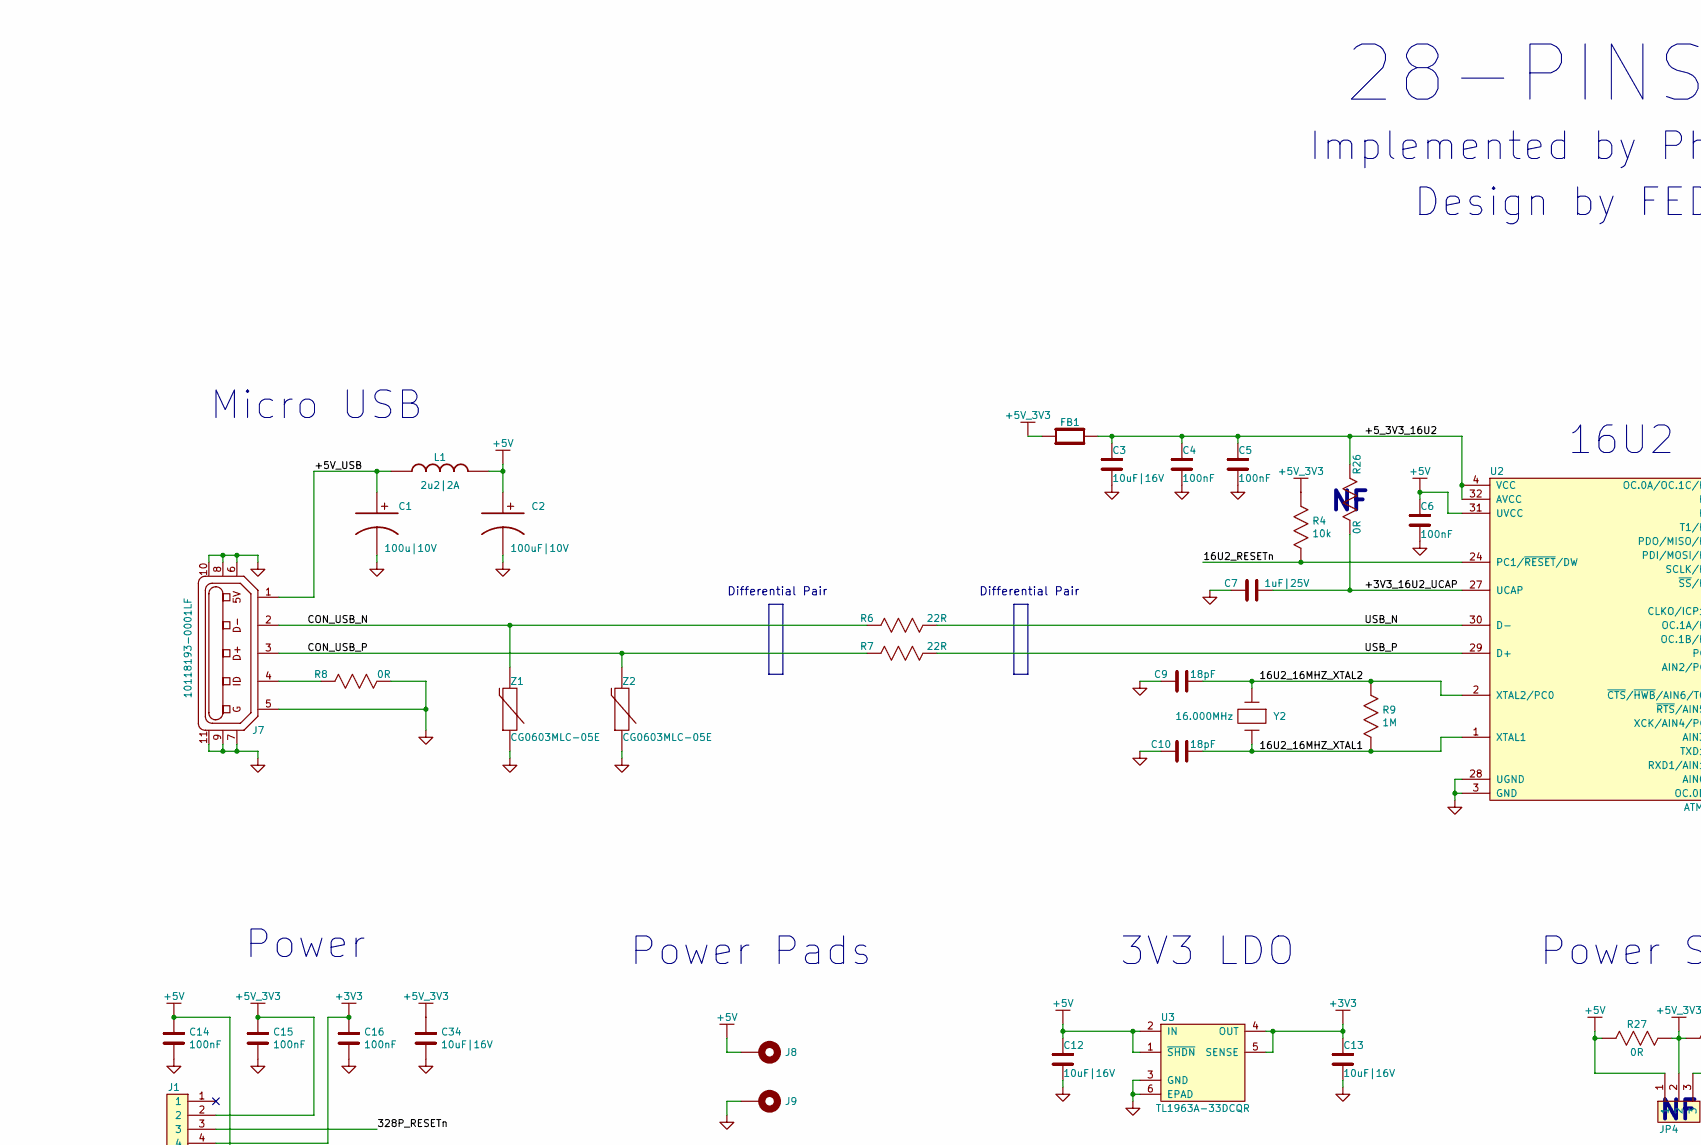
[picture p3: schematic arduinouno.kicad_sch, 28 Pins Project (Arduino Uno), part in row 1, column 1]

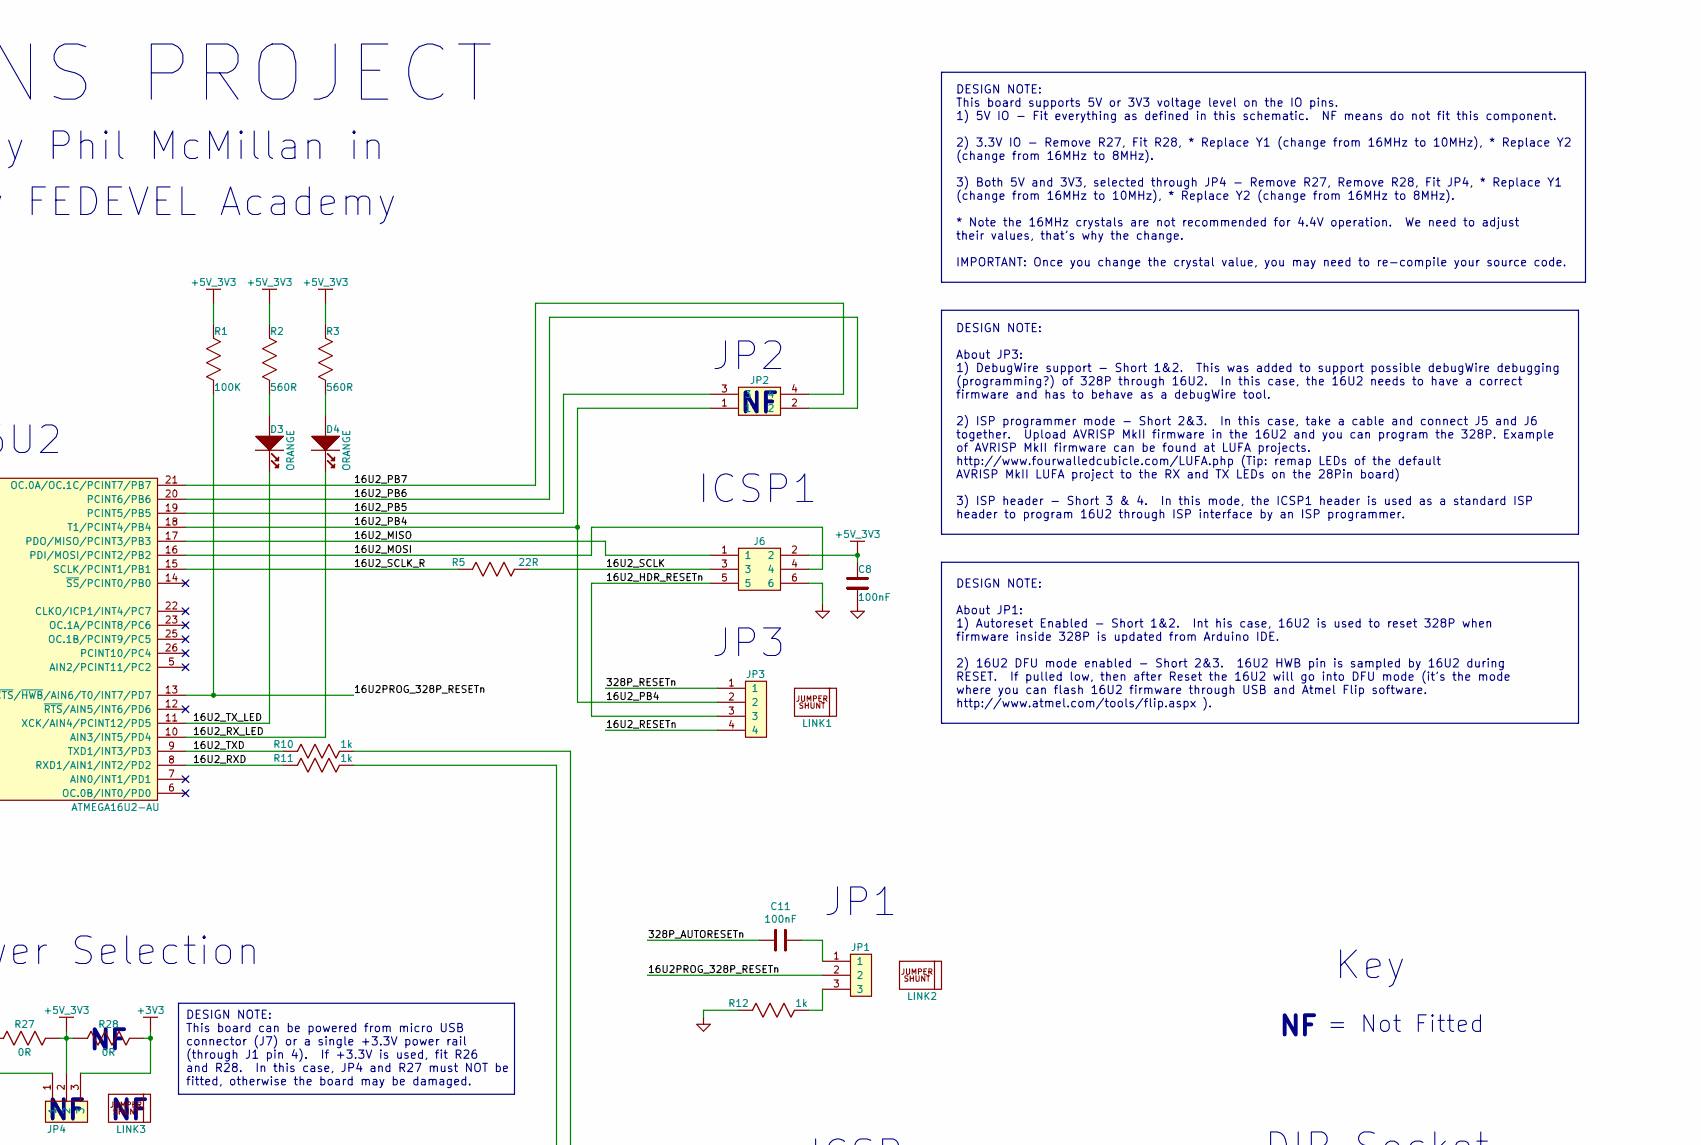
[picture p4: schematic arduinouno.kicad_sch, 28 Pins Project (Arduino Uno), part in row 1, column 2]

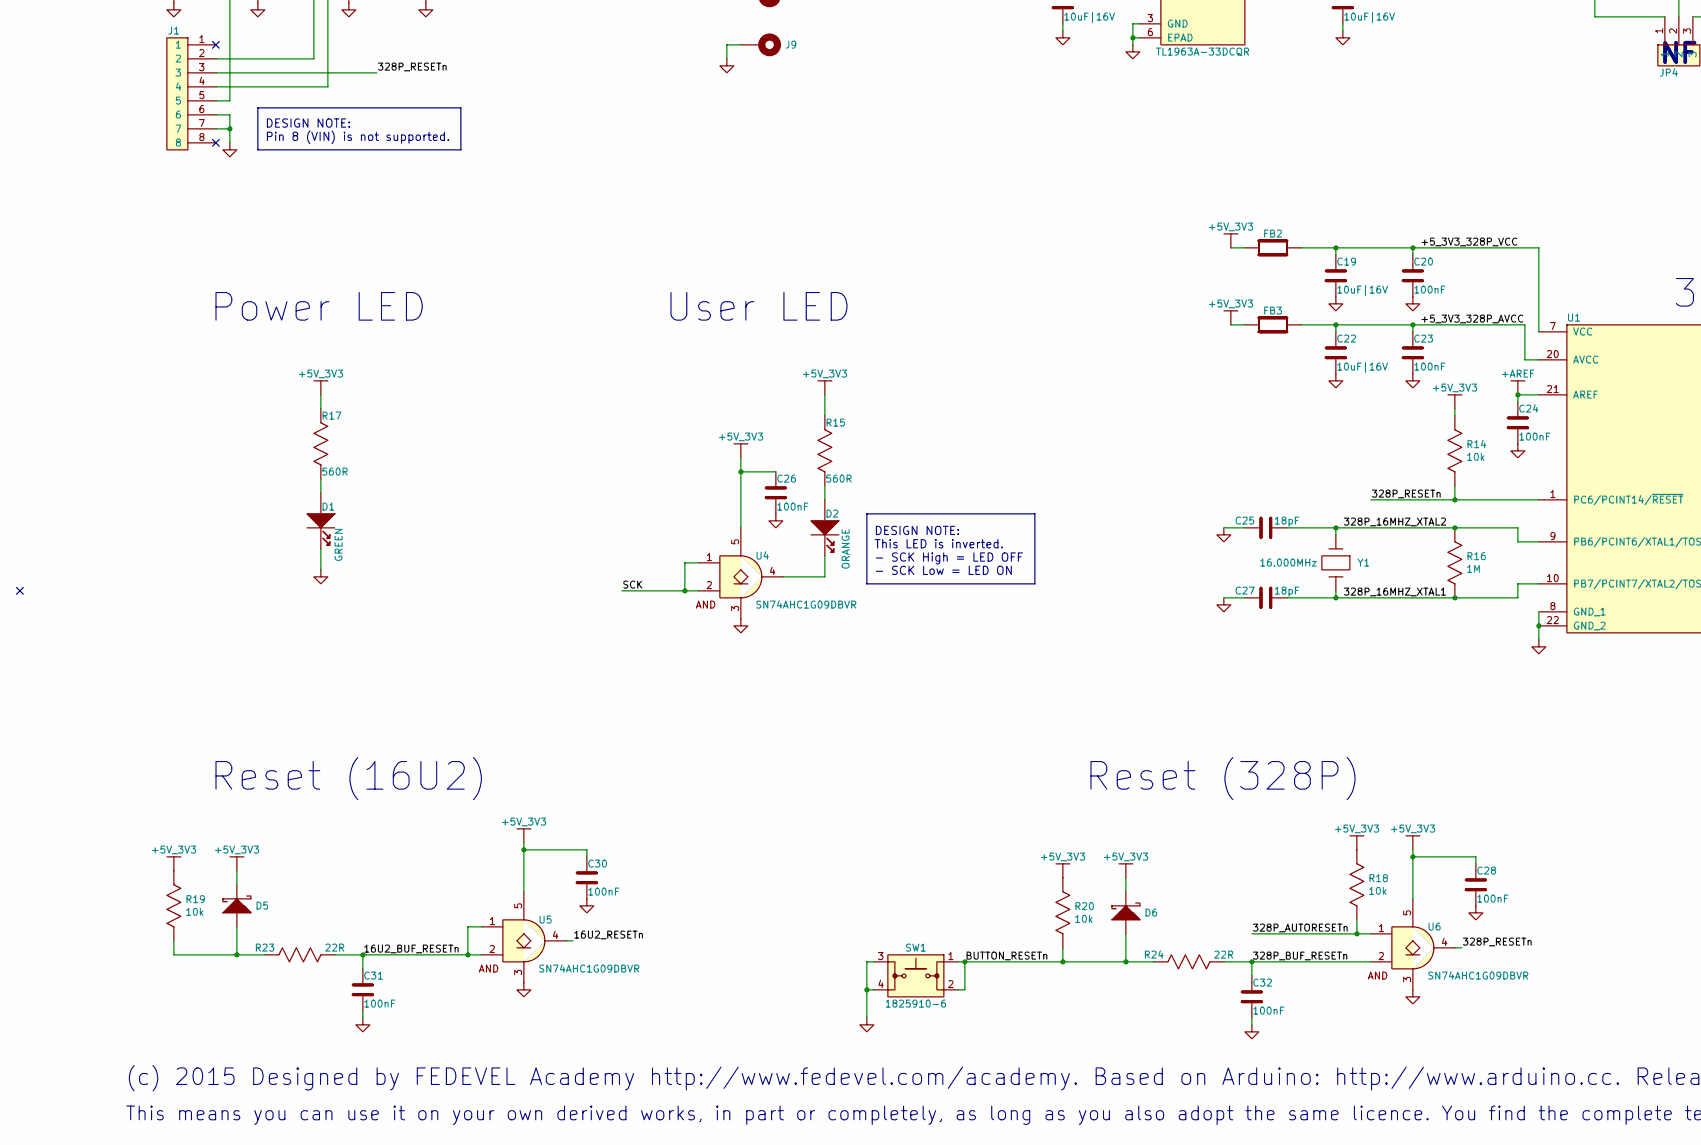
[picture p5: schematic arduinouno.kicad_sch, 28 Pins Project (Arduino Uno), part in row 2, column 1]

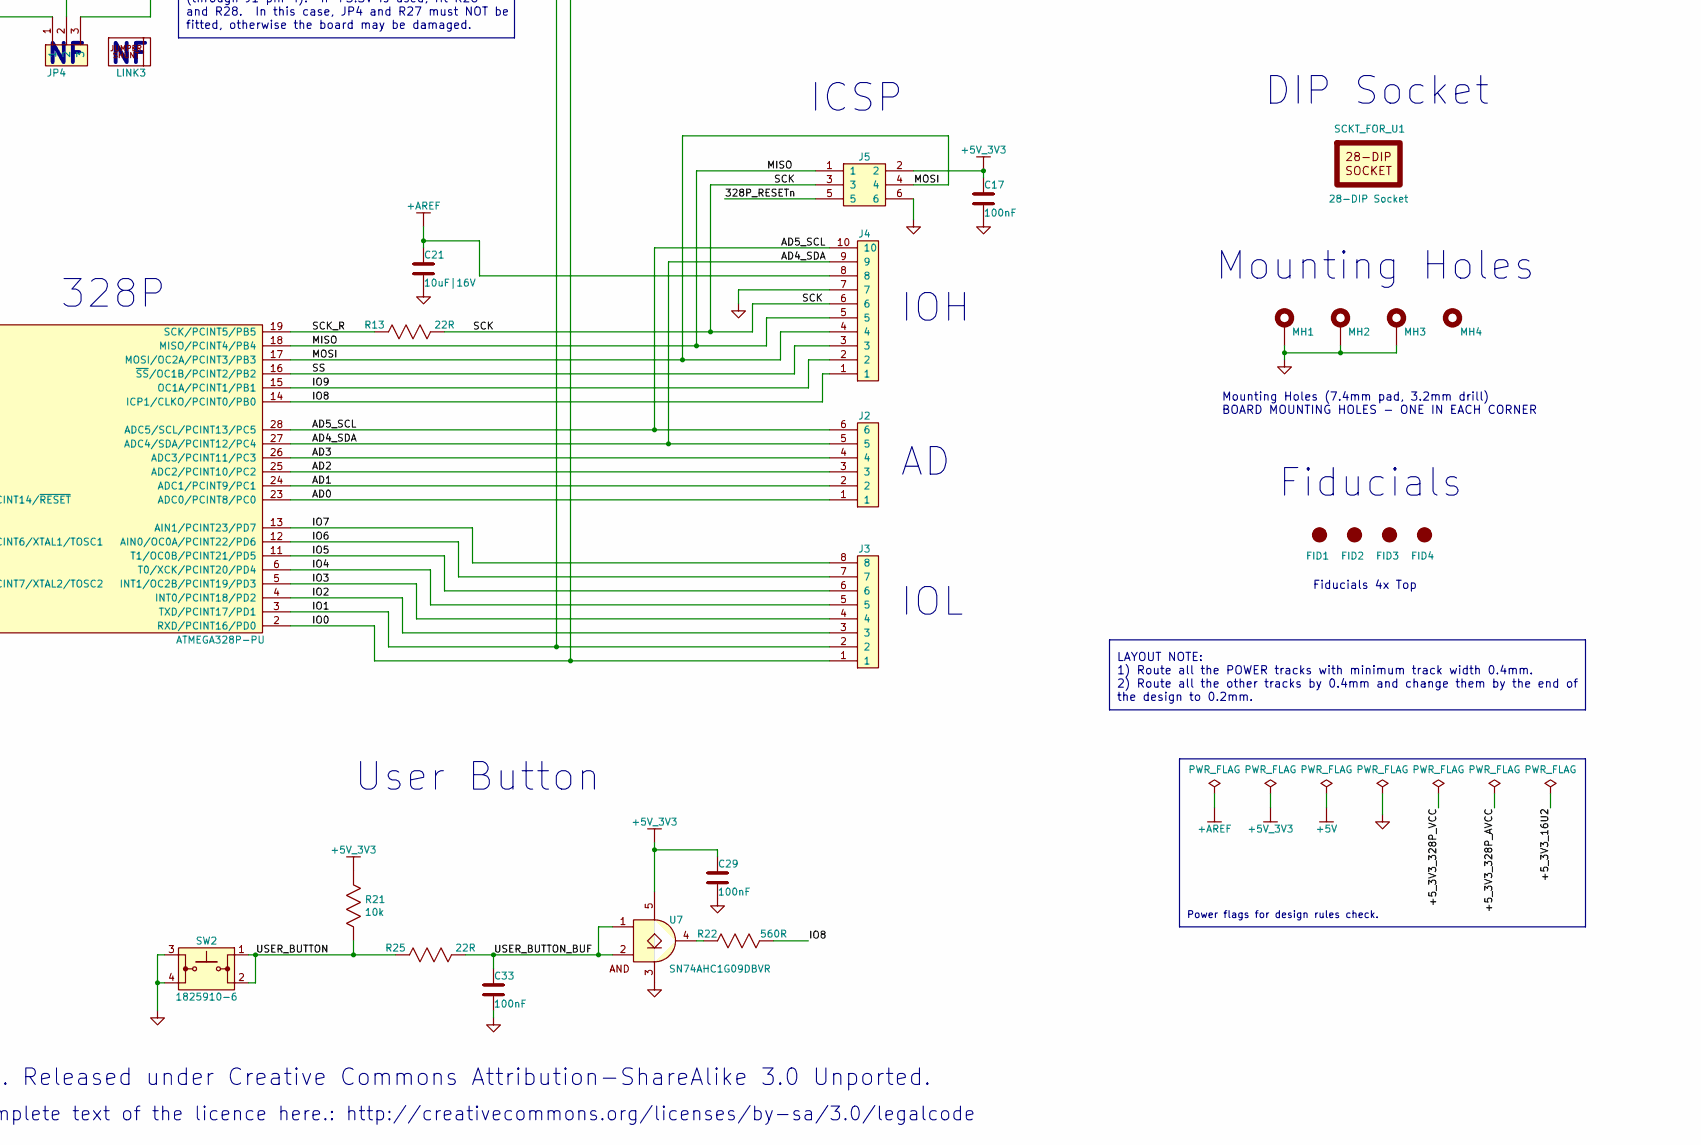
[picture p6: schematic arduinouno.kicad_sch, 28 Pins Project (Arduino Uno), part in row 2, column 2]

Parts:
C1: 100u|10V; C_ALUM_C_SIZE; Digikey PCE3867TR-ND
C2: 100uF|10V; C_ALUM_C_SIZE; Digikey PCE3867TR-ND
C3, C12, C13, C19, C21, C22, C34: 10uF|16V; C0805x145mm; Digikey 445-7645-1-ND
C4, C5, C6, C8, C11, C14, C15, C16, C17, C20, C23, C24, C26, C28, C29, C30, C31, C32, C33: 100nF; C0805x95mm; Digikey 445-7534-1-ND
C7: 1uF|25V; C0805x95mm; Digikey 445-1419-1-ND
C9, C10, C25, C27: 18pF; C0805x95mm; Digikey 399-8029-1-ND
D1: GREEN; LED_0603; Digikey 475-2709-1-ND
D2, D3, D4: ORANGE; LED_0603; Digikey 475-2740-1-ND
D5, D6: BAT54HT1G; SOD323; Digikey BAT54HT1GOSTR-ND
FB1, FB2, FB3: MPZ2012S601AT000; FB0805x85mm; Digikey 445-7645-1-ND
FID1, FID2, FID3, FID4: FID_1MM; FID_40x120M
J1, J3: M20-7820842; 8P_Header_Female_2.54mm; Digikey 952-1823-ND
J2: M20-7820646; 6P_Header_Female_2.54mm; Digikey 952-1809-ND
J4: M20-7821046; 10P_Header_Female_2.54mm; Digikey 952-1847-ND
J5, J6: 67997-106HLF; HDR_2x3_2.54mm; Digikey 609-3393-ND
J7: 10118193-0001LF; 10118193; Digikey 609-4616-1-ND
J8, J9: PAD_WITH_HOLE_4mmx1.5mm
JP1, JP4: 68000-103HLF; 3P_Header_2.54mm; Digikey 609-3461-ND
JP2: 68602-104HLF; HDR_2x2_2.54mm; Digikey 609-3361-ND
JP3: 68001-204HLF; 4P_Header_2.54mm; Digikey 609-3402-ND
L1: 2u2|2A; C1210_INDUCTOR; Digikey 399-9598-1-ND
LINK1, LINK2, LINK3: QPC02SXGN-RC; Digikey S9337-ND
MH1, MH2, MH3: MH_7.4MMCx3.2MMD
MH4: MH_7.4MMNCx3.2MMD; MH_7.4MMCx3.2MMD_NON_COPPER_NPTH
R1: 100K; R0805x60mm; Digikey 311-100KCRCT-ND
R2, R3, R15, R17, R22: 560R; R0805x60mm; Digikey 311-560CRCT-ND
R4, R14, R18, R19, R20, R21: 10k; R0805x60mm; Digikey 311-10.0KCRCT-ND
R5, R6, R7, R13, R23, R24, R25: 22R; R0805x60mm; Digikey 311-22.0CRCT-ND
R8, R26, R27, R28: 0R; R0805x60mm; Digikey 311-0.0ARCT-ND
R9, R16: 1M; R0805x60mm; Digikey 311-1.00MCRCT-ND
R10, R11, R12: 1k; R0805x60mm; Digikey 311-1.00KCRCT-ND
SCKT_FOR_U1: 28-DIP Socket; 28DIP_7.62MM_SCKT; Digikey 3M5480-ND
SW1, SW2: 1825910-6; Digikey 450-1650-ND
U1: ATMEGA328P-PU; 28PIN_PDIP_7.62mm; Digikey ATMEGA328P-PU-ND
U2: ATMEGA16U2-AU; QFP-32_8.4x8.4_Pitch0.8mm; Digikey ATMEGA16U2-AU-ND
U3: TL1963A-33DCQR; DCQ_R-PDSO-G6; Digikey 296-24534-1-ND
U4, U5, U6, U7: SN74AHC1G09DBVR; DBV_SOT23_5; Digikey 296-29202-1-ND
Y1, Y2: 16.000MHz; ABM7_BIG; Digikey 535-9840-1-ND
Z1, Z2: CG0603MLC-05E; R_0603; Digikey CG0603MLC-05ECT-ND

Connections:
+3V3: C13.1, C16.1, J1.4, JP4.3, R28.2, U3.4 (OUT), U3.5 (SENSE)
+5V: C2.1, C6.1, C12.1, C14.1, J1.5, J8.1, JP4.1, L1.2, R27.1, U2.31 (UVCC), U3.1 (~SHDN), U3.2 (IN)
+5V_3V3: C8.1, C15.1, C17.1, C26.1, C28.1, C29.1, C30.1, C34.1, D5.1 (Cathode), D6.1 (Cathode), FB1.1, FB2.1, FB3.1, J1.2, J5.2, J6.2, JP4.2, R1.1, R2.1, R3.1, R4.1, R14.1, R15.1, R17.1, R18.1, R19.1, R20.1, R21.1, R27.2, R28.1, U4.5 (VCC), U5.5 (VCC), U6.5 (VCC), U7.5 (VCC)
+AREF: C21.1, C24.1, J4.8, U1.21 (AREF)
/16U2PROG_328P_RESETn: JP1.2, R1.2, U2.13 (~CTS/~HWB/AIN6/T0/INT7/PD7)
/16U2_16MHZ_XTAL1: C10.2, R9.2, U2.1 (XTAL1), Y2.2
/16U2_16MHZ_XTAL2: C9.2, R9.1, U2.2 (XTAL2/PC0), Y2.1
/16U2_BUF_RESETn: C31.1, R23.2, U5.1 (A), U5.2 (B)
/16U2_HDR_RESETn: J6.5, JP3.3
/16U2_MISO: J6.1, U2.17 (PDO/MISO/PCINT3/PB3)
/16U2_MOSI: J6.4, U2.16 (PDI/MOSI/PCINT2/PB2)
/16U2_PB4: JP2.1, JP3.2, U2.18 (T1/PCINT4/PB4)
/16U2_PB5: JP2.3, U2.19 (PCINT5/PB5)
/16U2_PB6: JP2.2, U2.20 (PCINT6/PB6)
/16U2_PB7: JP2.4, U2.21 (OC.0A/OC.1C/PCINT7/PB7)
/16U2_RESETn: JP3.4, R4.2, U2.24 (PC1/~RESET/DW), U5.4 (Y)
/16U2_RXD: R11.1, U2.8 (RXD1/AIN1/INT2/PD2)
/16U2_RX_LED: D4.1 (Cathode), U2.10 (AIN3/INT5/PD4)
/16U2_SCLK: J6.3, R5.2
/16U2_SCLK_R: R5.1, U2.15 (SCLK/PCINT1/PB1)
/16U2_TXD: R10.1, U2.9 (TXD1/INT3/PD3)
/16U2_TX_LED: D3.1 (Cathode), U2.11 (XCK/AIN4/PCINT12/PD5)
/328P_16MHZ_XTAL1: C27.2, R16.2, U1.10 (PB7/PCINT7/XTAL2/TOSC2), Y1.2
/328P_16MHZ_XTAL2: C25.2, R16.1, U1.9 (PB6/PCINT6/XTAL1/TOSC1), Y1.1
/328P_AUTORESETn: C11.1, R18.2, U6.1 (A)
/328P_BUF_RESETn: C32.1, R24.2, U6.2 (B)
/328P_RESETn: J1.3, J5.5, JP3.1, R14.2, U1.1 (PC6/PCINT14/~RESET), U6.4 (Y)
/+3V3_16U2_UCAP: C7.2, R26.2, U2.27 (UCAP)
/+5V_USB: C1.1, J7.1, L1.1
/+5_3V3_16U2: C3.1, C4.1, C5.1, FB1.2, R26.1, U2.4 (VCC), U2.32 (AVCC)
/+5_3V3_328P_AVCC: C22.1, C23.1, FB3.2, U1.20 (AVCC)
/+5_3V3_328P_VCC: C19.1, C20.1, FB2.2, U1.7 (VCC)
/AD0: J2.1, U1.23 (ADC0/PCINT8/PC0)
/AD1: J2.2, U1.24 (ADC1/PCINT9/PC1)
/AD2: J2.3, U1.25 (ADC2/PCINT10/PC2)
/AD3: J2.4, U1.26 (ADC3/PCINT11/PC3)
/AD4_SDA: J2.5, J4.9, U1.27 (ADC4/SDA/PCINT12/PC4)
/AD5_SCL: J2.6, J4.10, U1.28 (ADC5/SCL/PCINT13/PC5)
/BUTTON_RESETn: D6.2 (Anode), R20.2, R24.1, SW1.1, SW1.2
/CON_USB_N: J7.2, R6.1, Z1.2
/CON_USB_P: J7.3, R7.1, Z2.2
/IO0: J3.1, R10.2, U1.2 (RXD/PCINT16/PD0)
/IO1: J3.2, R11.2, U1.3 (TXD/PCINT17/PD1)
/IO2: J3.3, U1.4 (INT0/PCINT18/PD2)
/IO3: J3.4, U1.5 (INT1/OC2B/PCINT19/PD3)
/IO4: J3.5, U1.6 (T0/XCK/PCINT20/PD4)
/IO5: J3.6, U1.11 (T1/OC0B/PCINT21/PD5)
/IO6: J3.7, U1.12 (AIN0/OC0A/PCINT22/PD6)
/IO7: J3.8, U1.13 (AIN1/PCINT23/PD7)
/IO8: J4.1, R22.2, U1.14 (ICP1/CLKO/PCINT0/PB0)
/IO9: J4.2, U1.15 (OC1A/PCINT1/PB1)
/MISO: J4.5, J5.1, U1.18 (MISO/PCINT4/PB4)
/MOSI: J4.4, J5.4, U1.17 (MOSI/OC2A/PCINT3/PB3)
/SCK: J4.6, J5.3, R13.2, U4.1 (A), U4.2 (B)
/SCK_R: R13.1, U1.19 (SCK/PCINT5/PB5)
/SS: J4.3, U1.16 (~SS/OC1B/PCINT2/PB2)
/USB_N: R6.2, U2.30 (D-)
/USB_P: R7.2, U2.29 (D+)
/USER_BUTTON: R21.2, R25.1, SW2.1, SW2.2
/USER_BUTTON_BUF: C33.1, R25.2, U7.1 (A), U7.2 (B)
GND: C1.2, C2.2, C3.2, C4.2, C5.2, C6.2, C7.1, C8.2, C9.1, C10.1, C12.2, C13.2, C14.2, C15.2, C16.2, C17.2, C19.2, C20.2, C21.2, C22.2, C23.2, C24.2, C25.1, C26.2, C27.1, C28.2, C29.2, C30.2, C31.2, C32.2, C33.2, C34.2, D1.1 (Cathode), J1.6, J1.7, J4.7, J5.6, J6.6, J7.5, J7.6, J7.7, J7.8, J7.9, J7.10, J7.11, J9.1, MH1.1, MH2.1, MH3.1, R8.2, R12.1, SW1.3, SW1.4, SW2.3, SW2.4, U1.8 (GND_1), U1.22 (GND_2), U2.3 (GND), U2.28 (UGND), U3.3 (GND), U3.6 (EPAD), U4.3 (GND), U5.3 (GND), U6.3 (GND), U7.3 (GND), Z1.1, Z2.1
unnamed: C11.2, JP1.1
unnamed: D1.2 (Anode), R17.2
unnamed: D2.1 (Cathode), U4.4 (Y)
unnamed: D2.2 (Anode), R15.2
unnamed: D3.2 (Anode), R2.2
unnamed: D4.2 (Anode), R3.2
unnamed: D5.2 (Anode), R19.2, R23.1
unnamed: J7.4, R8.1
unnamed: JP1.3, R12.2
unnamed: R22.1, U7.4 (Y)

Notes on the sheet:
Reset (328P)
This means you can use it on your own derived works, in part or completely, as long as you also adopt the same licence. You find the complete text of the licence here.: http://creativecommons.org/licenses/by-sa/3.0/legalcode
Power Pads
Fiducials
Key
Power Selection
16U2
(c) 2015 Designed by FEDEVEL Academy http://www.fedevel.com/academy. Based on Arduino: http://www.arduino.cc. Released under Creative Commons Attribution-ShareAlike 3.0 Unported.
28-PINS PROJECT
IOH
Implemented by Phil McMillan in
User Button
DESIGN NOTE: This board supports 5V or 3V3 voltage level on the IO pins. 1) 5V IO - Fit everything as defined in this schematic. NF means do not fit this component. 2) 3.3V IO - Remove R27, Fit R28, * Replace Y1 (change from 16MHz to 10MHz), * Replace Y2 (change from 16MHz to 8MHz). 3) Both 5V and 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
Mounting Holes
Power LED
ICSP
Reset (16U2)
DESIGN NOTE: This LED is inverted. - SCK High = LED OFF - SCK Low = LED ON
Differential Pair
IOL
Design by FEDEVEL Academy
ICSP1
Power flags for design rules check.
328P
JP3
DESIGN NOTE: About JP1: 1) Autoreset Enabled - Short 1&2. Int his case, 16U2 is used to reset 328P when firmware inside 328P is updated from Arduino IDE. 2) 16U2 DFU mode enabled - Short 2&3. 16U2 HWB pin is sampled by 16U2 during RESET. If pulled low, then after Reset the 16U2 will go into DFU mod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
DESIGN NOTE: This board can be powered from micro USB connector (J7) or a single +3.3V power rail (through J1 pin 4). If +3.3V is used, fit R26 and R28. In this case, JP4 and R27 must NOT be fitted, otherwise the board may be damaged.
DIP Socket
User LED
DESIGN NOTE: Pin 8 (VIN) is not supported.
Mounting Holes (7.4mm pad, 3.2mm drill) BOARD MOUNTING HOLES - ONE IN EACH CORNER
LAYOUT NOTE: 1) Route all the POWER tracks with minimum track width 0.4mm. 2) Route all the other tracks by 0.4mm and change them by the end of the design to 0.2mm.
Fiducials 4x Top
DESIGN NOTE: About JP3: 1) DebugWire support - Short 1&2. This was added to support possible debugWire debugging (programming?) of 328P through 16U2. In this case, the 16U2 needs to have a correct firmware and has to behave as a debugWire tool. 2) ISP programmer mode - Short 2&3. In this case, take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
JP1
Power
3V3 LDO
JP2
= Not Fitted
Micro USB

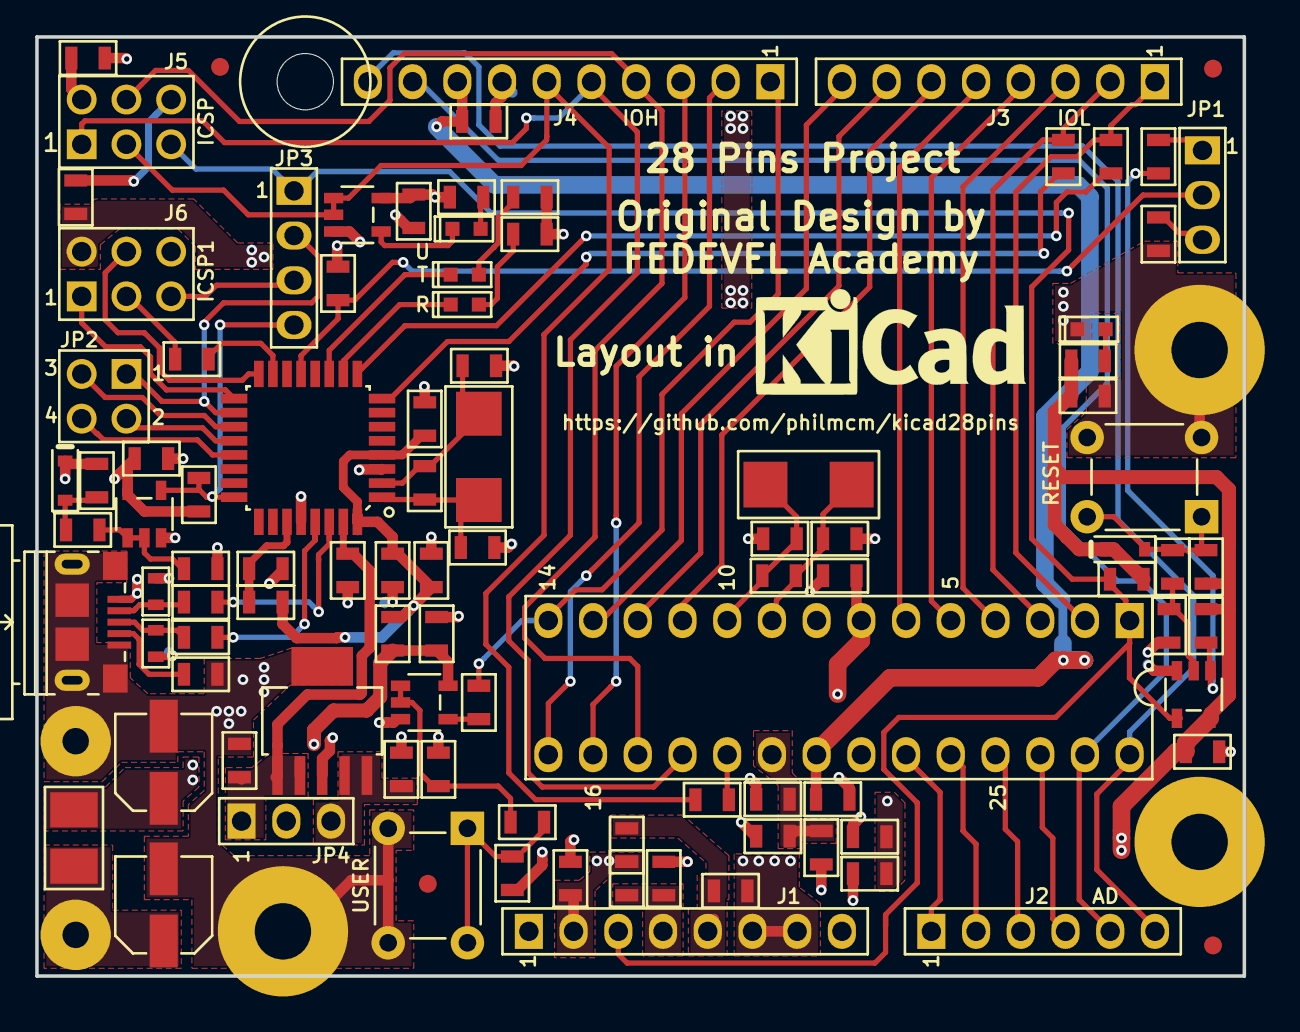
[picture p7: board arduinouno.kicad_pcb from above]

Board: 2 copper layers, 68.6 x 53.3 mm, 106 parts (0 on the bottom side), 71 nets.

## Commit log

2018-09-15 Schematic and README updates
    [arduinouno.sch]
2018-09-16 Completed schematic capture
    [arduinouno.csv, arduinouno.sch]
2018-09-16 Added schematic pdf, updated missing R26
    [arduinouno.sch]
2018-09-17 started placement; updated 3d model offsets for PDIP components
    [arduinouno.kicad_pcb]
2018-09-18 finished placement
    [arduinouno.kicad_pcb]
2018-09-19 updated design rules and net classes
    [arduinouno.kicad_pcb]
2018-09-20 layout continuing
    [arduinouno.kicad_pcb]
2018-09-23 routed power nets 5V, 3V3, 5/3V3
    [arduinouno.kicad_pcb]
2018-09-23 updated ground vias
    [arduinouno.kicad_pcb]
2018-09-23 power polys done, before ground poly
    [arduinouno.kicad_pcb]
2018-09-23 after ground poly
    [arduinouno.kicad_pcb]
2018-09-24 improved layout, almost complete
    [arduinouno.kicad_pcb]
2018-09-24 completed layout, drc ok
    [arduinouno.kicad_pcb]
2018-09-25 updated silkscreen
    [arduinouno.kicad_pcb]
2018-09-25 added gerbers
    [arduinouno-B.Cu.gbl, arduinouno-B.Mask.gbs, arduinouno-B.Paste.gbp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]
2018-09-25 fixed errors on silkscreen
    [arduinouno.kicad_pcb]
2018-09-25 added assembly drawing
2018-09-25 fixed R27/R28 overlap on F.Fab layer
    [arduinouno.kicad_pcb]
2018-09-25 updates to f.fab and assembly drawing
    [arduinouno.kicad_pcb]
2023-04-05 Updated project and symbol library to kicad 7.0
2023-04-05 Updated schematic to Kicad 7.0
    [arduinouno.kicad_sch, arduinouno.sch]
2023-04-05 Updated pcb layout to Kicad 7.0
    [arduinouno.kicad_pcb]

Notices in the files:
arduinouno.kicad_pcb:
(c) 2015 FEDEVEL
